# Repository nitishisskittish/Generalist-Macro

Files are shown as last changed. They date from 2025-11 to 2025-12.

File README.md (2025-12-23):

## **Astrapad**
---
A 7 key macropad with a rotary encoder, OLED screen, and 16 WS2812B LED’s. Currently runs on KMK firmware

### **Features**
---
- Two Piece 3D Printable Case
- 128x32 OLED Display
- EC11 Rotary encoder
- 16 WS2812B RGB LEDs, probably waaayyy too much, but the more the merrier I guess
- 7 Keys

### **CAD Model**
---
The case is held together by 4 M3 Bolts and heatset inserts, 1 in each corner. The bottom half of the case has a built in tilt. Originally I designed this with see-through plastic “windows” in mind, but as of now those windows have been replaced with direct holes looking into the PCB. Maybe I’ll add them later.

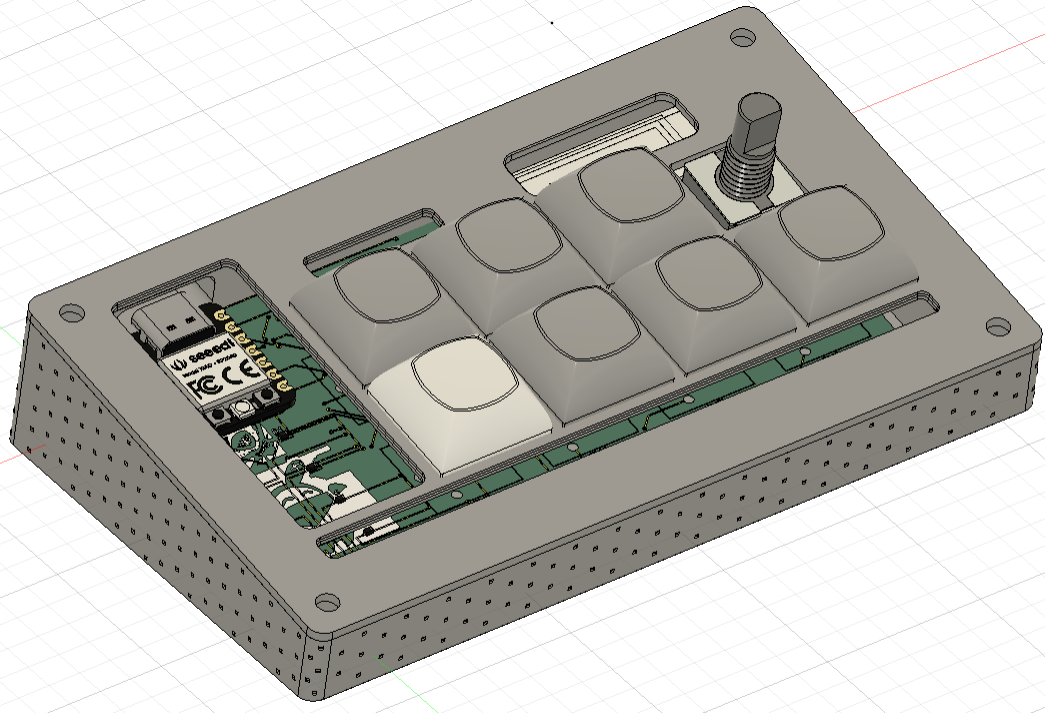
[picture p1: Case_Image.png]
Case


### **PCB**
---
I made my PCB in KiCad. I got the bangboo silkscreen arts from the [Zenless Zone Zero Fandom Sticker Page](https://zenless-zone-zero.fandom.com/wiki/Stickers), and the pikachu art from [pixlecheese](https://www.pixilart.com/art/pikachu-thunderbolt-1a236168d6612c3)

- Schematic:

  Schematic
- PCB:

  PCB
- My favorite part of the whole project tbh, made me feel very smart. Also if you're interested the numbers at the very bottom are binary, although it doesn’t spell out anything that interesting

### **Firmware**
---
Currently Astrapad runs on KMK, but I plan on switching to QMK later because I want to add [VIA](https://caniusevia.com/) support
- The rotary encoder changes the volume, and you can tap it to toggle mute
- The top left and top right keys skips forward or backward respectively in the playback queue
- The top middle button and bottom 3 buttons act as WASD keys, with the top middle button being the W Key
- The bottom right button is currently mapped to a custom shortcut I have on my computer that opens Spotify
- The OLED Screen displays the current volume level of whatever device the macropad is currently connected to
- I have a list of features I want to add commented in the KMK main.py file if you're interested in that
### **BOM**
---
- 1x Seeed XIAO RP2040
- 1x 0.91 inch OLED displays 
- 1x EC11 rotary encoders
- 1x Case (2 3D printed parts)
- 1x 3D printed EC11 (Rotary Encoder) Knob
- 4x M3x5x4 Heatset inserts
- 4x M3x16mm screws
- 7x Cherry MX Switches
- 7x DSA keycaps
- 8x Through-hole 1N4148 Diodes
- 16x SK6812 MINI-E LEDs

### **Extra Stuff**
---
The example I’m basing this README off of had this section, so I’m adding it too. 
Thanks a lot to the Blueprint Hackclub slack, I probably wouldn’t have finished this project without their help.
Ummm yeah, that’s it I guess.

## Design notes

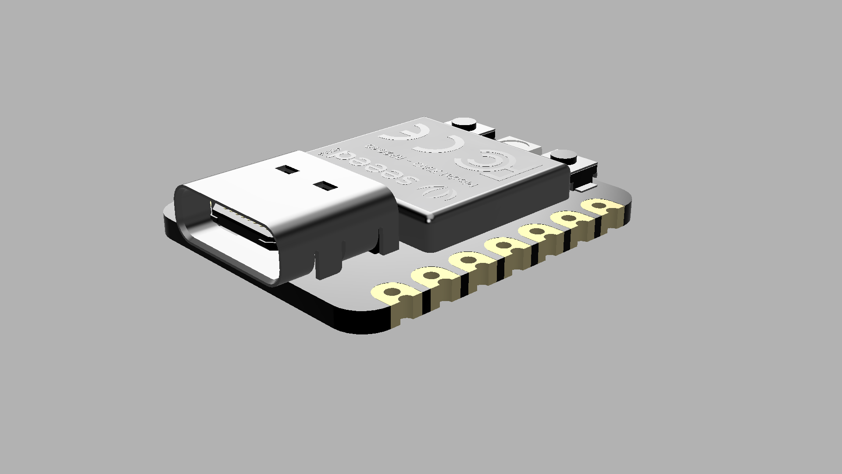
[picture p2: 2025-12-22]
CAD/3D Models/seeed-studio-xiao-rp2040-3d-model/Seeed Studio XIAO RP2040_2.png

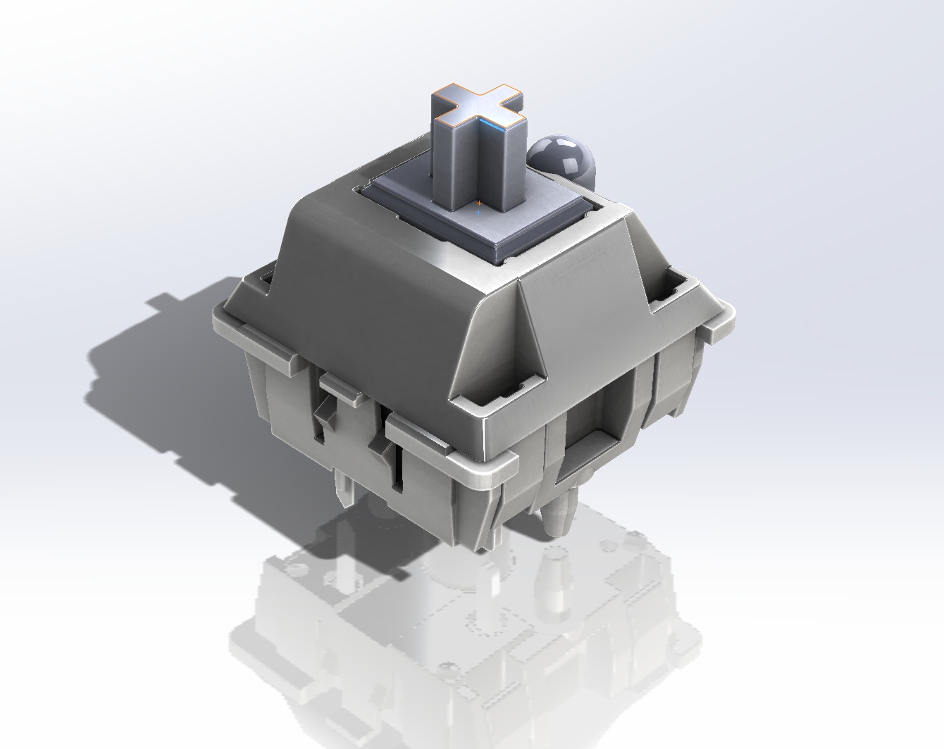
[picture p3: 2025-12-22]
CAD/3D Models/cherry-mx-switches-mx-1.snapshot.16/Renderings/屏幕截图(23).jpg

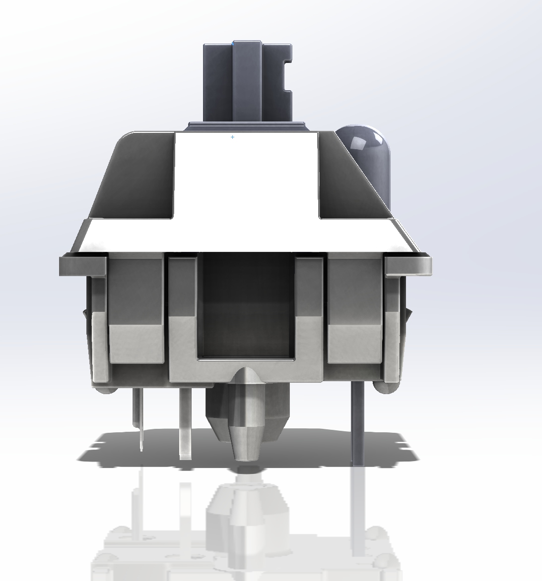
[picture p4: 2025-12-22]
CAD/3D Models/cherry-mx-switches-mx-1.snapshot.16/Renderings/屏幕截图(26).jpg

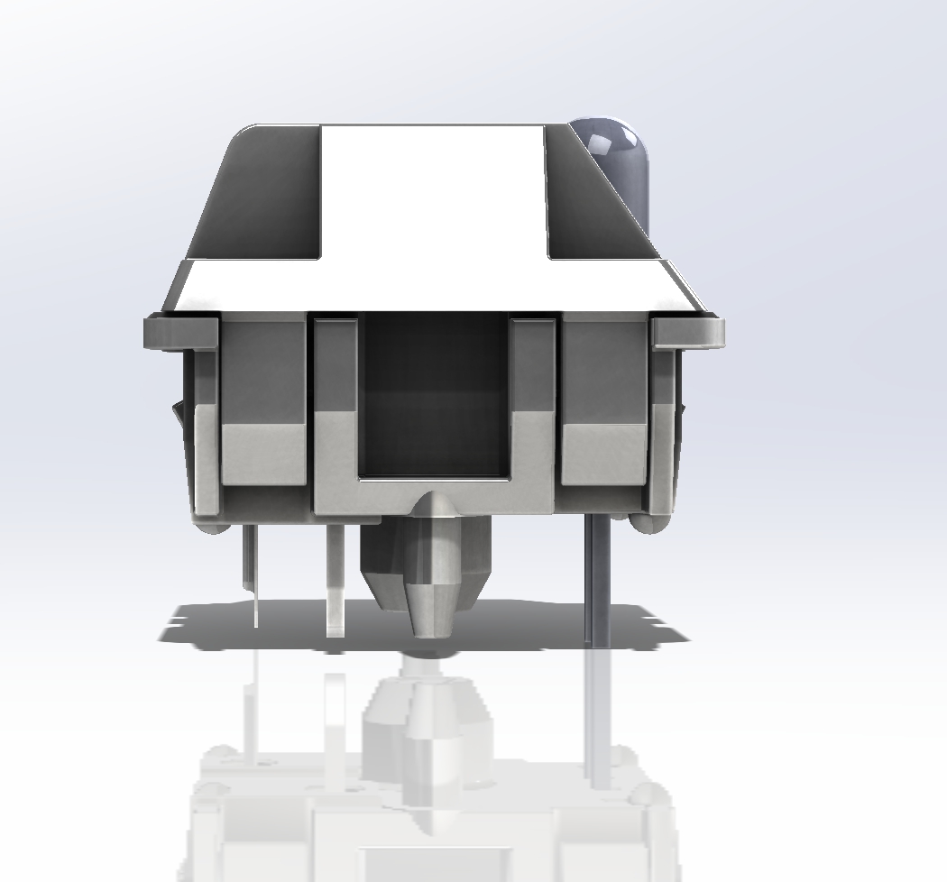
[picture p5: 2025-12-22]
CAD/3D Models/cherry-mx-switches-mx-1.snapshot.16/Renderings/屏幕截图(22).jpg

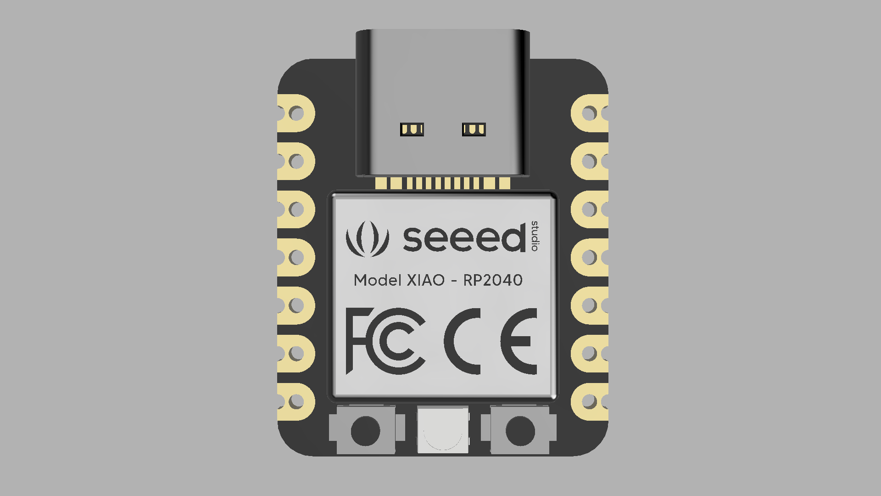
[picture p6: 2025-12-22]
CAD/3D Models/seeed-studio-xiao-rp2040-3d-model/Seeed Studio XIAO RP2040_1.png

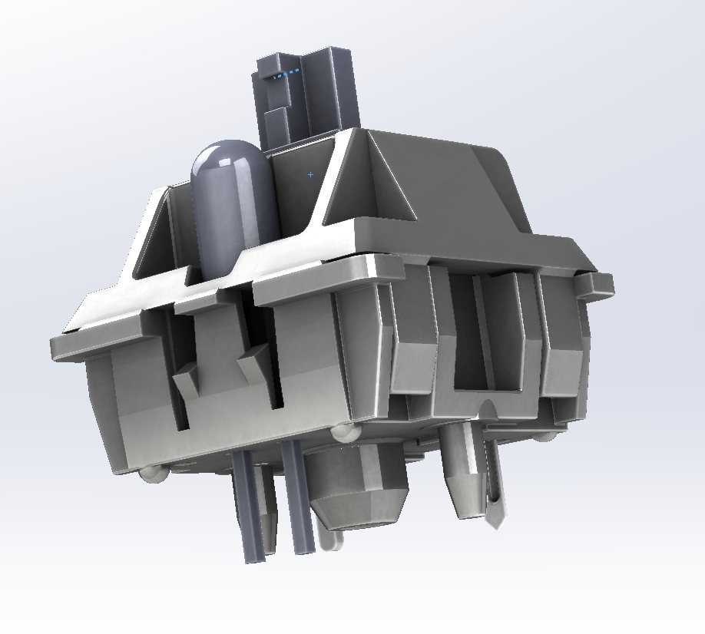
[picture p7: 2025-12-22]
CAD/3D Models/cherry-mx-switches-mx-1.snapshot.16/Renderings/屏幕截图(25).jpg

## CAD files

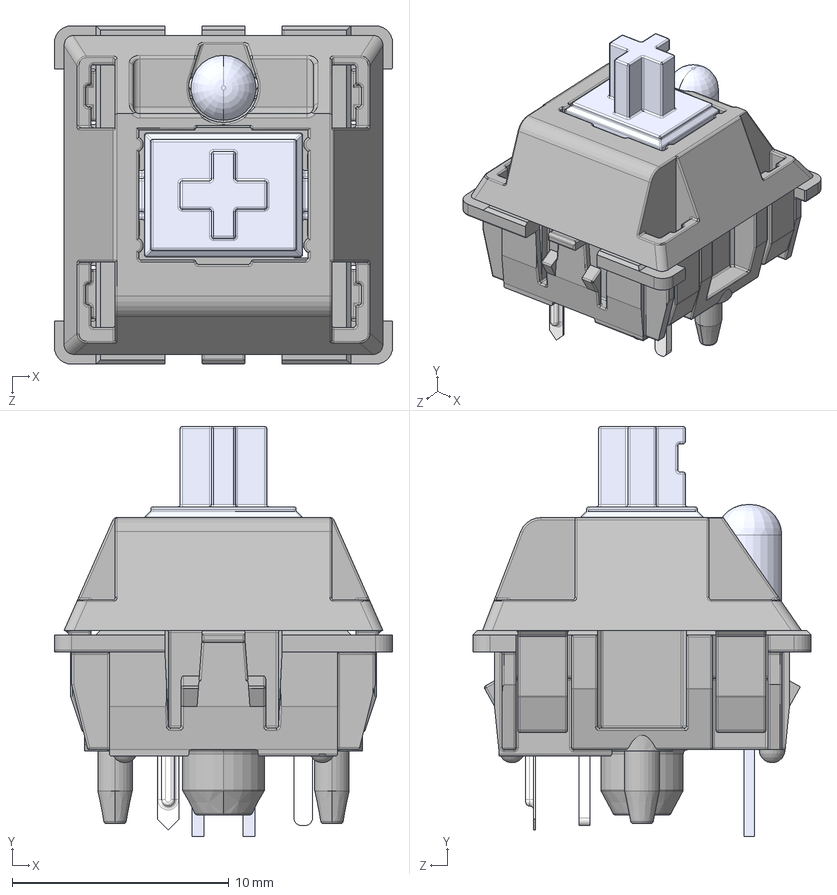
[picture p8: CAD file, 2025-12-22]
CAD/3D Models/cherry-mx-switches-mx-1.snapshot.16/MX .STEP
15.6 x 18.9 x 15.6 mm
MX 轴 按键′_ü___¨1
MX 轴 轴体áì_¨￠¨__
MX粣 拸簽LEDLEDLED
MX轴 轴体 底部 μ×2__默认_á2____è_
针脚___默认__è_

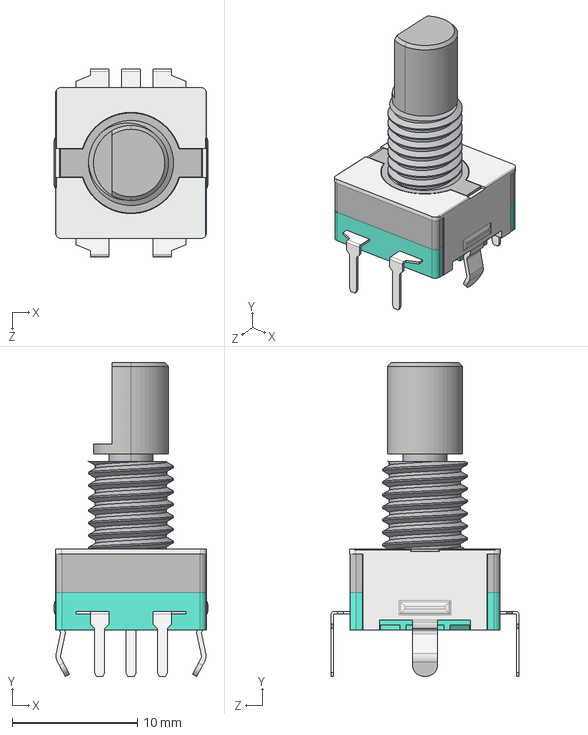
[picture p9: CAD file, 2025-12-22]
CAD/3D Models/rotary-encoder-17.snapshot.2/旋转编码器.STEP
12.3 x 25.1 x 15.0 mm

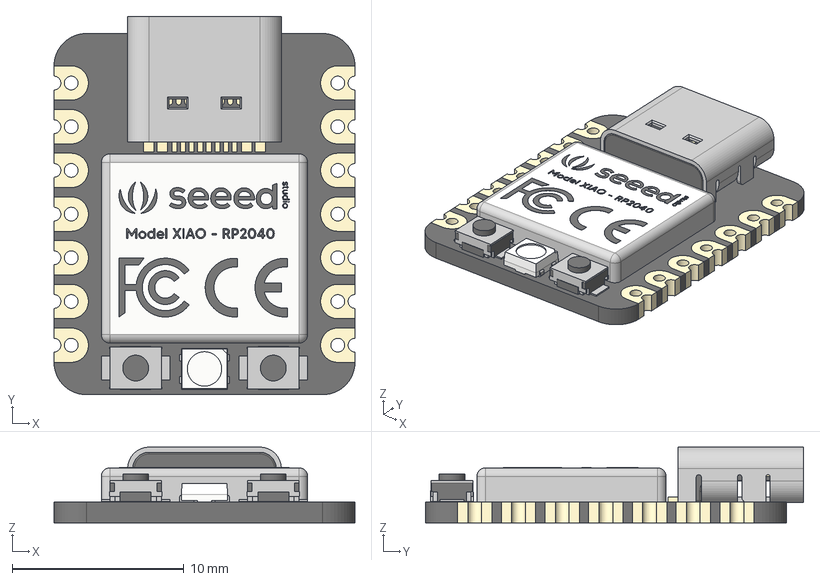
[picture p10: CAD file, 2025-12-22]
CAD/3D Models/seeed-studio-xiao-rp2040-3d-model/Seeed Studio XIAO RP2040 v26.step
17.5 x 22.0 x 4.40 mm
type-c v2
smd_button v3
DOUT
DIN
VSS
VDD
smd_button v3(Mirror)

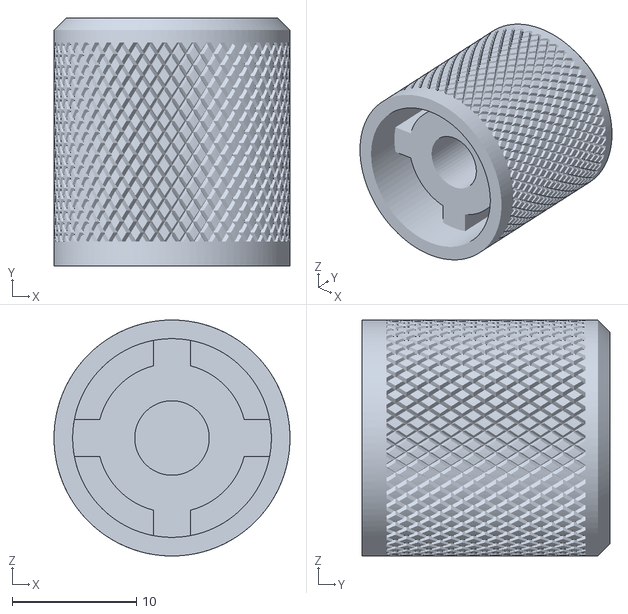
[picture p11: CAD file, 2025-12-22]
CAD/3D Models/rotary-encoder-17.snapshot.2/d19h20-knurled-encoder-knobs-champfered-top.stl
19.0 x 20.0 x 19.0

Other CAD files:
CAD/3D Models/rotary-encoder-17.snapshot.2/旋转编码器.SLDPRT
CAD/3D Models/seeed-studio-xiao-rp2040-3d-model/Seeed Studio XIAO RP2040 v26.f3d

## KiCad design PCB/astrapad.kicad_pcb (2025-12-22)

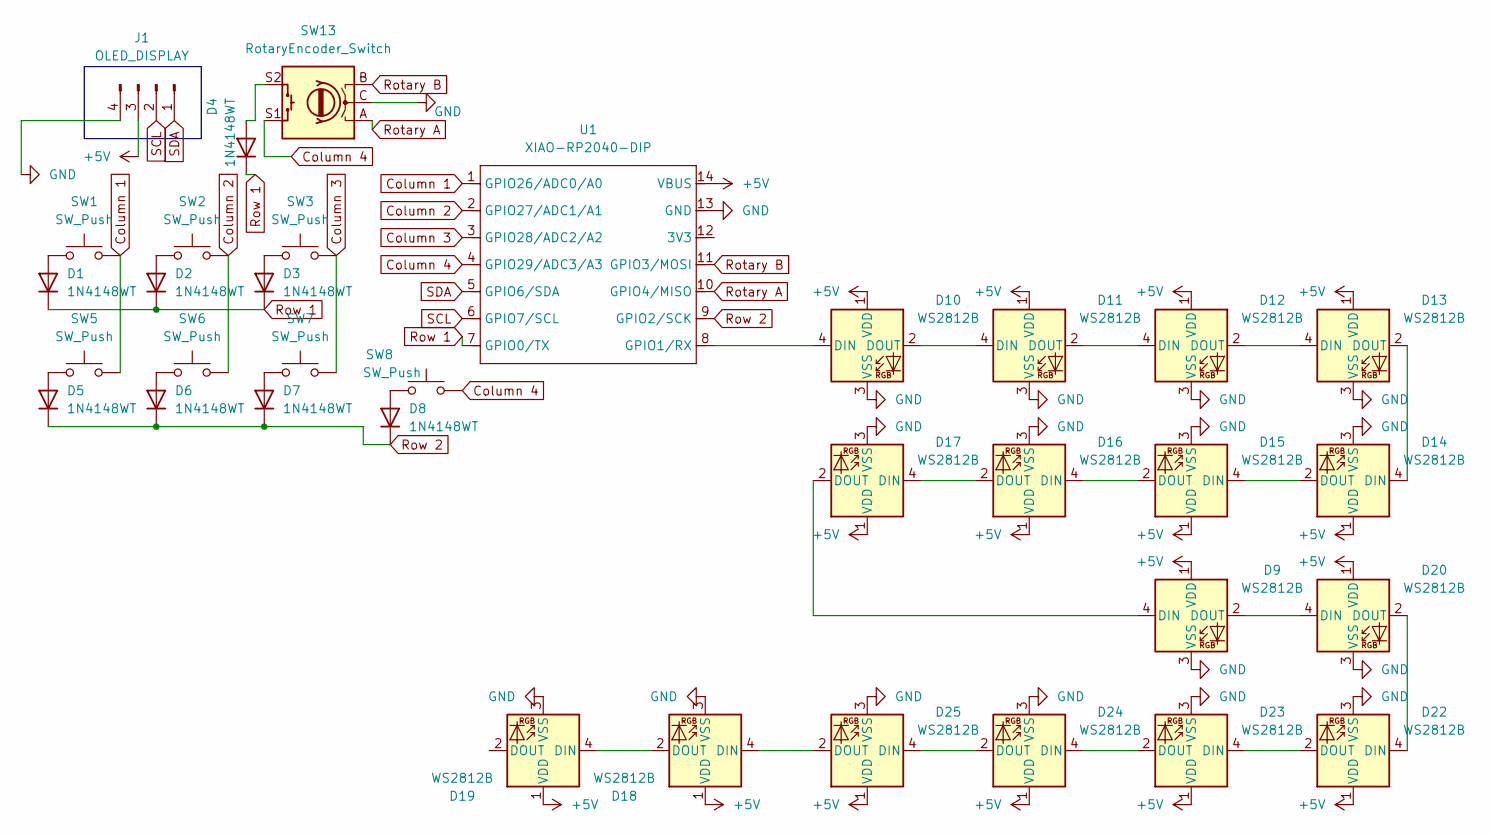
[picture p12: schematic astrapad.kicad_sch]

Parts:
D1, D2, D3, D4, D5, D6, D7, D8: 1N4148WT; D_SOD-523
D9, D17, D18, D19, D20, D22, D23, D24, D25: WS2812B; LED_SK6812MINI_PLCC4_3.5x3.5mm_P1.75mm
D10, D11, D12, D13, D14, D15, D16: WS2812B; MX_SK6812MINI-E_REV
J1: OLED_DISPLAY; PinHeader_1x04_P2.54mm_Vertical
SW1, SW2, SW3, SW5, SW6, SW7, SW8: SW_Push; SW_Cherry_MX_1.00u_PCB
SW13: RotaryEncoder_Switch; RotaryEncoder_Alps_EC11E-Switch_Vertical_H20mm
U1: XIAO-RP2040-DIP

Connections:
+5V: D9.1 (VDD), D10.1 (VDD), D11.1 (VDD), D12.1 (VDD), D13.1 (VDD), D14.1 (VDD), D15.1 (VDD), D16.1 (VDD), D17.1 (VDD), D18.1 (VDD), D19.1 (VDD), D20.1 (VDD), D22.1 (VDD), D23.1 (VDD), D24.1 (VDD), D25.1 (VDD), J1.3, U1.14 (VBUS)
Column 1: SW1.2, SW5.2, U1.1 (GPIO26/ADC0/A0)
Column 2: SW2.2, SW6.2, U1.2 (GPIO27/ADC1/A1)
Column 3: SW3.2, SW7.2, U1.3 (GPIO28/ADC2/A2)
Column 4: SW8.2, SW13.S1, U1.4 (GPIO29/ADC3/A3)
GND: D9.3 (VSS), D10.3 (VSS), D11.3 (VSS), D12.3 (VSS), D13.3 (VSS), D14.3 (VSS), D15.3 (VSS), D16.3 (VSS), D17.3 (VSS), D18.3 (VSS), D19.3 (VSS), D20.3 (VSS), D22.3 (VSS), D23.3 (VSS), D24.3 (VSS), D25.3 (VSS), J1.4, SW13.C, U1.13 (GND)
unnamed: D1.2 (A), SW1.1
unnamed: D2.2 (A), SW2.1
unnamed: D3.2 (A), SW3.1
unnamed: D4.2 (A), SW13.S2
unnamed: D5.2 (A), SW5.1
unnamed: D6.2 (A), SW6.1
unnamed: D7.2 (A), SW7.1
unnamed: D8.2 (A), SW8.1
unnamed: D10.4 (DIN), U1.8 (GPIO1/RX)
unnamed: D10.2 (DOUT), D11.4 (DIN)
unnamed: D11.2 (DOUT), D12.4 (DIN)
unnamed: D12.2 (DOUT), D13.4 (DIN)
unnamed: D13.2 (DOUT), D14.4 (DIN)
unnamed: D14.2 (DOUT), D15.4 (DIN)
unnamed: D15.2 (DOUT), D16.4 (DIN)
unnamed: D16.2 (DOUT), D17.4 (DIN)
unnamed: D9.4 (DIN), D17.2 (DOUT)
unnamed: D18.4 (DIN), D25.2 (DOUT)
unnamed: D18.2 (DOUT), D19.4 (DIN)
unnamed: D9.2 (DOUT), D20.4 (DIN)
unnamed: D20.2 (DOUT), D22.4 (DIN)
unnamed: D22.2 (DOUT), D23.4 (DIN)
unnamed: D23.2 (DOUT), D24.4 (DIN)
unnamed: D24.2 (DOUT), D25.4 (DIN)
Rotary A: SW13.A, U1.10 (GPIO4/MISO)
Rotary B: SW13.B, U1.11 (GPIO3/MOSI)
Row 1: D1.1 (K), D2.1 (K), D3.1 (K), D4.1 (K), U1.7 (GPIO0/TX)
Row 2: D5.1 (K), D6.1 (K), D7.1 (K), D8.1 (K), U1.9 (GPIO2/SCK)
SCL: J1.2, U1.6 (GPIO7/SCL)
SDA: J1.1, U1.5 (GPIO6/SDA)

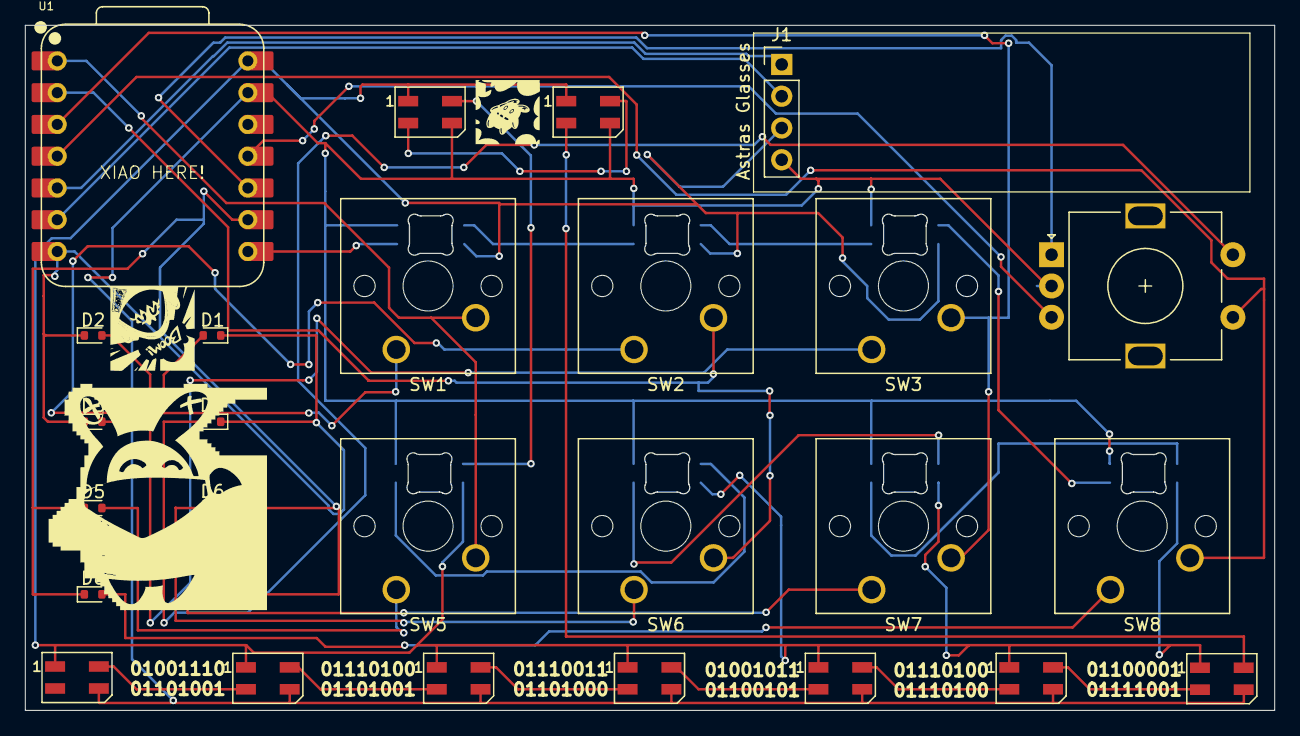
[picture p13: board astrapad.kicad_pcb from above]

Board: 2 copper layers, 99.9 x 54.8 mm, 34 parts (0 on the bottom side), 36 nets.

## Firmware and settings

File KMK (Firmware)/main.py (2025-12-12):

# Future Update List:
# Make it so that holding down the encoder and turning adjusts RGB Brightness.
# Make it so that holding down rightmost key and turning encoder adjusts RGB Color.
# Make it so that OLED Displays Brightness level when being adjusted 

import board
import digitalio
from kmk.kmk_keyboard import KMKKeyboard
from kmk.keys import KC
from kmk.matrix import DiodeOrientation
from kmk.extensions.rgb import RGB, RGBModes
from kmk.extensions.display.volume import VolumeDisplay
from kmk.extensions.display import Display
from kmk.modules.encoder import Encoder
from kmk.modules.layers import Layers
from kmk.extensions.media_keys import MediaKeys

keyboard = KMKKeyboard()

keyboard.extensions.append(MediaKeys())

# RGB LEDs:
rgb = RGB(
    pixel_pin=board.D7,
    num_pixels=16,
    hue=0,
    sat=0, 
    val=255, 
    mode=RGBModes.STATIC_COLOR,
    val_default=72
)
keyboard.extensions.append(rgb)

# OLED Volume Display
display_ext = Display(
    i2c_port=board.I2C(),
    display=VolumeDisplay(),
)
keyboard.extensions.append(display_ext)

# Layers (Right now I only have one, but I may add more later)
keyboard.modules.append(Layers())

# Rotary Encoder
keyboard.modules.append(Encoder(
    pins=((board.D9, board.D10, None),),
    tap_max=1000, 
    on_clockwise=KC.VOLU, 
    on_ccwise=KC.VOLD, 
))


# Key Matrix
keyboard.row_pins = (board.D6, board.D8)
keyboard.col_pins = (board.D0, board.D1, board.D2, board.D3)
keyboard.diode_orientation = DiodeOrientation.COL2ROW


# Keymap
KEYMAP = [
    [
        KC.MPRV, KC.W,    KC.MNXT, KC.MUTE,
        KC.A,    KC.S,    KC.D,    KC.LGUI(KC.S) # Custom shortcut key for opening spotify on my system
    ]
]
keyboard.keymaps = KEYMAP

if __name__ == '__main__':
    keyboard.go()

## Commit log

2025-11-29 Finished Schematic, Started PCB
    [Generalist_Macro.kicad_pcb, Generalist_Macro.kicad_sch]
2025-11-30 PCB laid out and wired. I just have to add the **Aesthetic** silkscreens now
    [Generalist_Macro-B_Cu.gbr, Generalist_Macro-B_Mask.gbr, Generalist_Macro-B_Paste.gbr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]
2025-12-06 Fixed 3D Model of PCB in FreeCAD Turns out the knob isn't centered properly, so I'll have to fix that later. In other news, I really shouldn't be awake this late...
    [Seeed Studio XIAO RP2040 v26.f3d, astrapad.FCStd, astrapad.kicad_pcb]
2025-12-07 Switching from FreeCAD to Fusion360 Due to the several and constant issues I'm having with FreeCAD, I will be switching to Fusion360 If you wish to know why I was using FreeCAD in the first place, it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
    [astrapad.kicad_pcb]
2025-12-11 Repositioned Key Backlight LEDS
    [astrapad.kicad_pcb]
2025-12-12 Some PCB Rerouting And by "some", I mean all of it. I didn't account for the size of the actual OLED screen (just had the pins before), so I had to reroute basically everything once I did.
    [astrapad.kicad_pcb, astrapad.kicad_sch]
2025-12-22 Case finished, going to start working on readme, syncing to desktop
    [MX .STEP, Seeed Studio XIAO RP2040 v26.f3d, Seeed Studio XIAO RP2040 v26.step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]
2025-12-22 A merge tragedy occurred...
    [MX .STEP, Seeed Studio XIAO RP2040 v26.f3d, Seeed Studio XIAO RP2040 v26.step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]
2025-12-22 Yeah....I forgot to update the footprints after updating the paths. Also all these commits are happening because I'm syncing files between my laptop and desktop through git
    [astrapad.kicad_pcb]
